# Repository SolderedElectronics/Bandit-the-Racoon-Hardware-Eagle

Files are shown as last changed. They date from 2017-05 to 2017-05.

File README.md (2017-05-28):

# Bandit the Racoon hardware (Eagle Files)
## Image
BTR image
[Bandit the Racoon board(101413)][board]

## Description and details
Bandit the Racoon is a cool looking board made for programming education which eliminates all need to work with hardware - everything is already connected and ready to use on the board. It can be programmed with block programming which is best for programming logic learning and with Arduino programming using Arduino library or using classic Arduino programming.
Onboard, there are many different sensors and actuators which can be used directly. All you need to do is connect the USB cable to the PC and you are ready to program and play! It supports battery power as well, there is battery charger onboard, so your projects can be portable.

###Specs:
- Temperature sensor
- Light sensor 
- Pushbutton
- Switch
- Potentiometer
- General input pins
- 12 RGB LED diodes arranged into a circle
- Buzzer
- General output pins
- I2C connector
- Atmega328 microcontroller
- CP2102 USB to UART bridge
- Lithium charger onboard

###Exact pins connections
If you wish to make your own Arduino code, here is list of all Arduino sensors and actuators and pins to which are they connected to. 
PINS

## Repository content
This repo contains Cadsoft Eagle .sch and .brd files for BTR board. It also contains schematic in .pdf created from .sch Eagle file. 
Files have been arranged into folders for navigating between different versions of board. 
Tip: layer 200 shows top silkscreen and layer 208 should be bottom silkscreen. tParts and bParts is not used.

## Docs
- [BTR product page][board]
- [BTR Arduino library][library]

## Board versions
- v1.0 - inital version

## License info
This product is open-source. Yay!
For any tech questions, contact us at techsupport@e-radionica.com
If you find an Issue, please open one at GitHub. If you can improve our product, fork it!

e-r.io Team.

[board]: https://e-radionica.com/en/bandit-the-raccoon-btr.html
[library]: https://github.com/e-radionicacom/Bandit-the-Racoon-Arduino-library

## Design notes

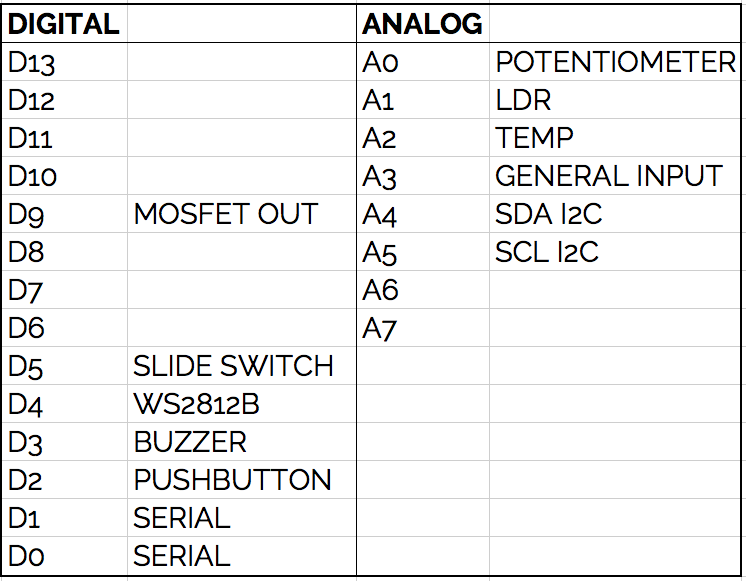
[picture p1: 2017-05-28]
v1.0/BTR_pins.png

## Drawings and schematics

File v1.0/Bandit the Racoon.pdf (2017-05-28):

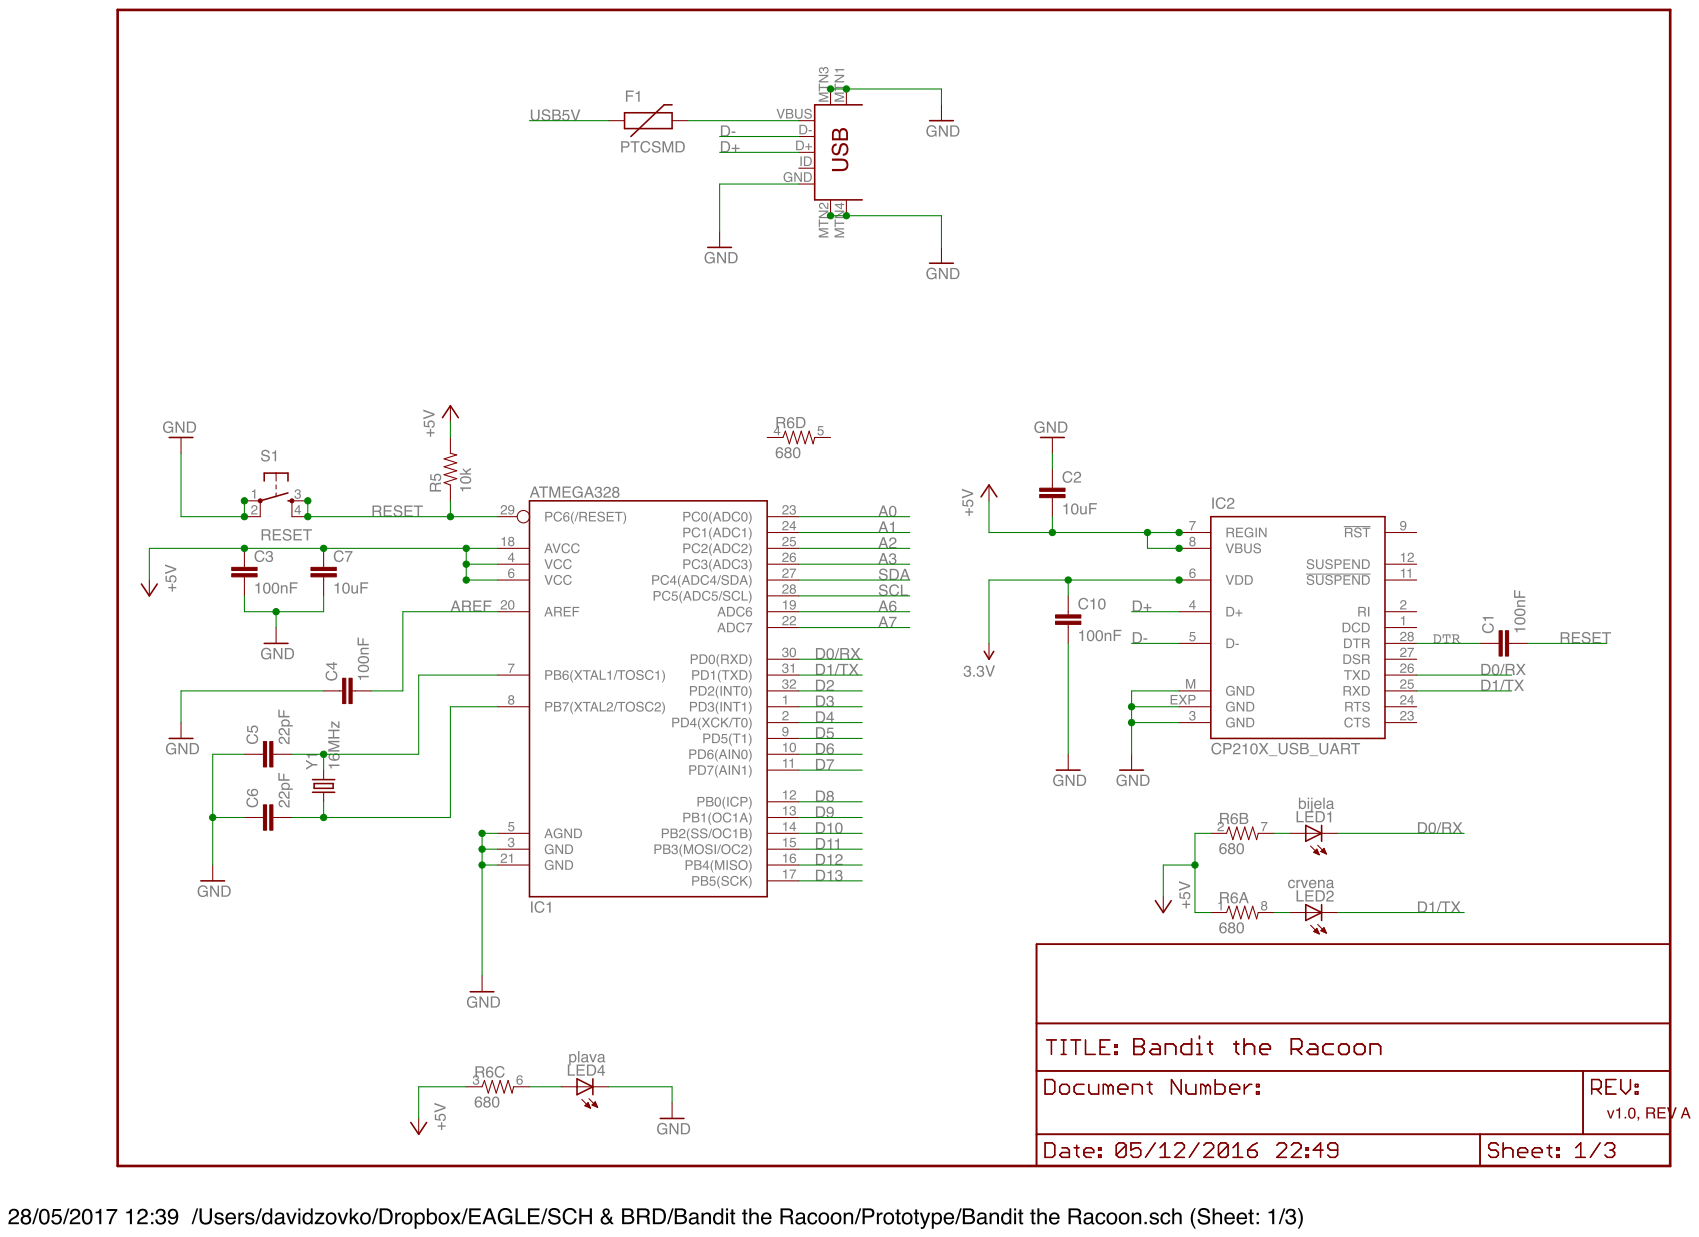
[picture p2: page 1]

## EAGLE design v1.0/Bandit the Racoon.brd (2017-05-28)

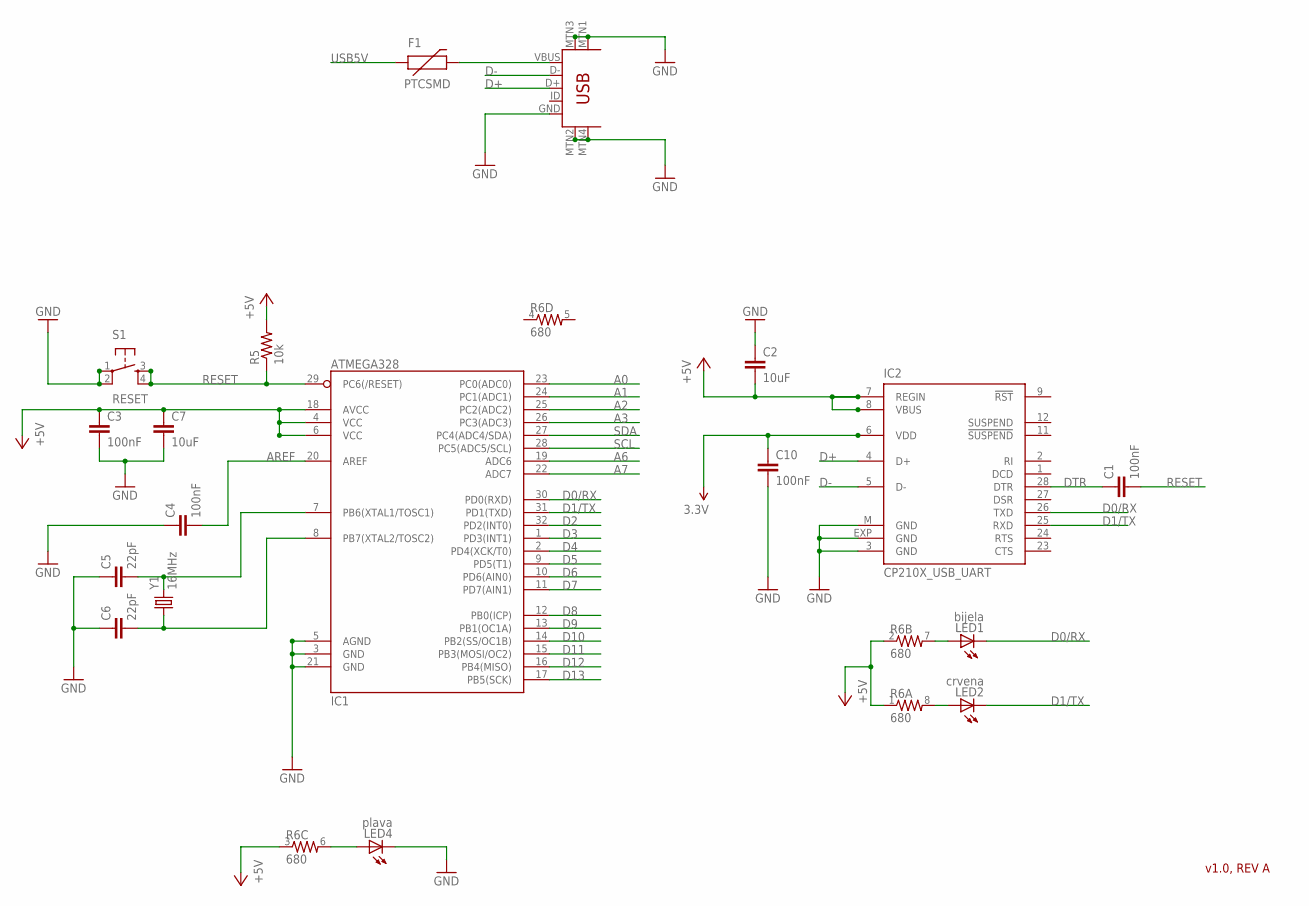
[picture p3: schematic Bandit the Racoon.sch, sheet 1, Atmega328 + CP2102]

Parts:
C1, C3, C4, C10: 100nF; 0603-CAP
C2, C7: 10uF; C3216
C5, C6: 22pF; 0603-CAP
F1: PTCSMD; PTC-1206
IC1: ATMEGA328; TQFP32-08
IC2: CP210X_USB_UART; MLP28
LED1: bijela; CHIP-LED0805
LED2: crvena; CHIP-LED0805
LED4: plava; CHIP-LED0805
R5: 10k; 0603-RES
R6: 680; 0603-ARV
S1: RESET; TACTILE_SWITCH_SMD
U1: USB-MINIB
Y1: 16MHz; CRYSTAL-SMD-5X3

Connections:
3.3V: C10.1, IC2.6 (VDD); also elsewhere on the board
+5V: C2.2, C3.1, C7.1, IC1.4 (VCC), IC1.6 (VCC), IC1.18 (AVCC), IC2.7 (REGIN), IC2.8 (VBUS), R5.2, R6.1, R6.2 (1), R6.3 (1); also elsewhere on the board
A0: IC1.23 (PC0(ADC0)); also elsewhere on the board
A1: IC1.24 (PC1(ADC1)); also elsewhere on the board
A2: IC1.25 (PC2(ADC2)); also elsewhere on the board
A3: IC1.26 (PC3(ADC3)); also elsewhere on the board
A6: IC1.19 (ADC6)
A7: IC1.22 (ADC7)
AREF: C4.2, IC1.20 (AREF)
CRYSTAL1: C5.2, IC1.7 (PB6(XTAL1/TOSC1)), Y1.3 (2)
CRYSTAL2: C6.2, IC1.8 (PB7(XTAL2/TOSC2)), Y1.1
D0/RX: IC1.30 (PD0(RXD)), IC2.26 (TXD), LED1.C; also elsewhere on the board
D1/TX: IC1.31 (PD1(TXD)), IC2.25 (RXD), LED2.C; also elsewhere on the board
D2: IC1.32 (PD2(INT0)); also elsewhere on the board
D3: IC1.1 (PD3(INT1)); also elsewhere on the board
D4: IC1.2 (PD4(XCK/T0)); also elsewhere on the board
D5: IC1.9 (PD5(T1)); also elsewhere on the board
D6: IC1.10 (PD6(AIN0))
D7: IC1.11 (PD7(AIN1))
D8: IC1.12 (PB0(ICP))
D9: IC1.13 (PB1(OC1A)); also elsewhere on the board
D10: IC1.14 (PB2(SS/OC1B))
D11: IC1.15 (PB3(MOSI/OC2))
D12: IC1.16 (PB4(MISO))
D13: IC1.17 (PB5(SCK))
D+: IC2.4 (D+), U1.D+
D-: IC2.5 (D-), U1.D-
DTR: C1.1, IC2.28 (DTR); also elsewhere on the board
GND: C2.1, C3.2, C4.1, C5.1, C6.1, C7.2, C10.2, IC1.3 (GND), IC1.5 (AGND), IC1.21 (GND), IC2.3 (GND), IC2.EXP (GND), IC2.M (GND), LED4.C, S1.1, S1.2, U1.GND, U1.MTN1 (MTN2), U1.MTN2 (MTN3), U1.MTN3 (MTN1), U1.MTN4; also elsewhere on the board
unnamed: LED1.A, R6.7 (2)
unnamed: LED2.A, R6.8 (2)
unnamed: F1.2, U1.VBUS
PLV_LED: LED4.A, R6.6 (2)
RESET: C1.2, IC1.29 (PC6(/RESET)), R5.1, S1.3, S1.4
SCL: IC1.28 (PC5(ADC5/SCL)); also elsewhere on the board
SDA: IC1.27 (PC4(ADC4/SDA)); also elsewhere on the board
USB5V: F1.1; also elsewhere on the board

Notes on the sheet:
v1.0, REV A

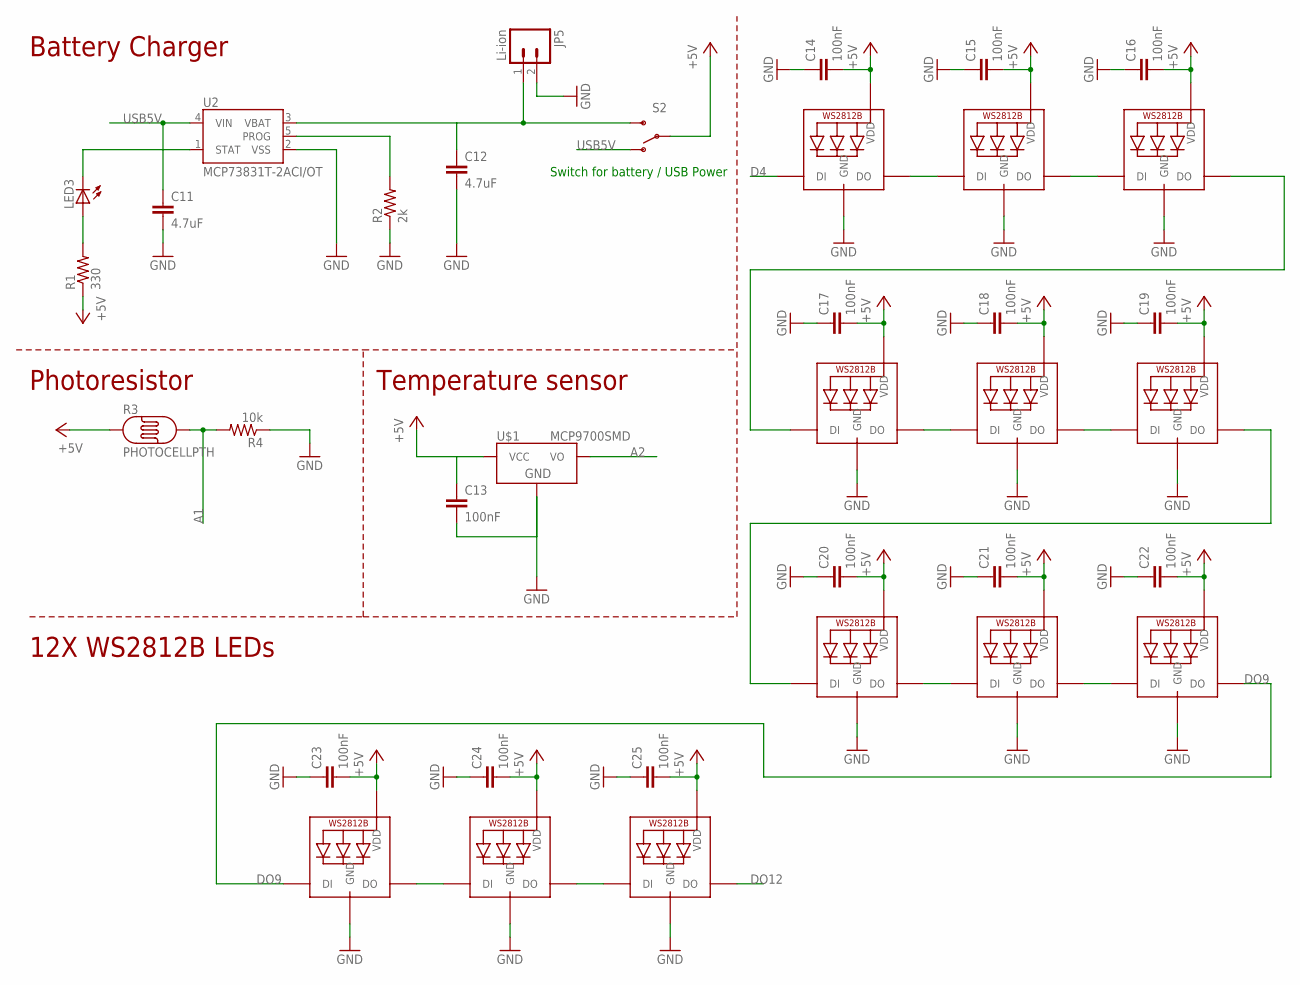
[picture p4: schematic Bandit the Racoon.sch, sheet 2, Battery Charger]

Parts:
C11, C12: 4.7uF; 0805
C13, C14, C15, C16, C17, C18, C19, C20, C21, C22, C23, C24, C25: 100nF; 0603-CAP
JP5: Li-ion; JST-2-PTH
LED3: LEDCHIPLED_0805; CHIPLED_0805
LED5, LED6, LED7, LED8, LED9, LED10, LED11, LED12, LED13, LED14, LED15, LED16: WS2812B5050; WS2812B
R1: 330; 0603-RES
R2: 2k; 0603-RES
R3: PHOTOCELLPTH; PHOTOCELL
R4: 10k; 0603-RES
S2: SWITCH-SPST-SMD-A
U2: MCP73831T-2ACI/OT; SOT23-5
U$1: MCP9700SMD; SOT23-3

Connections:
+5V: C13.1, C14.2, C15.2, C16.2, C17.2, C18.2, C19.2, C20.2, C21.2, C22.2, C23.2, C24.2, C25.2, LED5.1-VDD (VDD), LED6.1-VDD (VDD), LED7.1-VDD (VDD), LED8.1-VDD (VDD), LED9.1-VDD (VDD), LED10.1-VDD (VDD), LED11.1-VDD (VDD), LED12.1-VDD (VDD), LED13.1-VDD (VDD), LED14.1-VDD (VDD), LED15.1-VDD (VDD), LED16.1-VDD (VDD), R1.1, R3.1, S2.2, U$1.1 (VCC); also elsewhere on the board
A1: R3.2, R4.2; also elsewhere on the board
A2: U$1.2 (VO); also elsewhere on the board
D4: LED5.4-DIN (DI); also elsewhere on the board
DO1: LED5.2-DOUT (DO), LED6.4-DIN (DI)
DO2: LED6.2-DOUT (DO), LED7.4-DIN (DI)
DO3: LED7.2-DOUT (DO), LED8.4-DIN (DI)
DO4: LED8.2-DOUT (DO), LED9.4-DIN (DI)
DO5: LED9.2-DOUT (DO), LED10.4-DIN (DI)
DO6: LED10.2-DOUT (DO), LED11.4-DIN (DI)
DO7: LED11.2-DOUT (DO), LED12.4-DIN (DI)
DO8: LED12.2-DOUT (DO), LED13.4-DIN (DI)
DO9: LED13.2-DOUT (DO), LED14.4-DIN (DI)
DO10: LED14.2-DOUT (DO), LED15.4-DIN (DI)
DO11: LED15.2-DOUT (DO), LED16.4-DIN (DI)
DO12: LED16.2-DOUT (DO)
GND: C11.2, C12.2, C13.2, C14.1, C15.1, C16.1, C17.1, C18.1, C19.1, C20.1, C21.1, C22.1, C23.1, C24.1, C25.1, JP5.2, LED5.3-GND (GND), LED6.3-GND (GND), LED7.3-GND (GND), LED8.3-GND (GND), LED9.3-GND (GND), LED10.3-GND (GND), LED11.3-GND (GND), LED12.3-GND (GND), LED13.3-GND (GND), LED14.3-GND (GND), LED15.3-GND (GND), LED16.3-GND (GND), R2.1, R4.1, U2.2 (VSS), U$1.3 (GND); also elsewhere on the board
unnamed: LED3.C, U2.1 (STAT)
unnamed: LED3.A, R1.2
unnamed: C12.1, JP5.1, S2.3 (S), U2.3 (VBAT)
unnamed: R2.2, U2.5 (PROG)
USB5V: C11.1, S2.1 (O), U2.4 (VIN); also elsewhere on the board

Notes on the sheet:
Switch for battery / USB Power
Battery Charger
Photoresistor
Temperature sensor
12X WS2812B LEDs

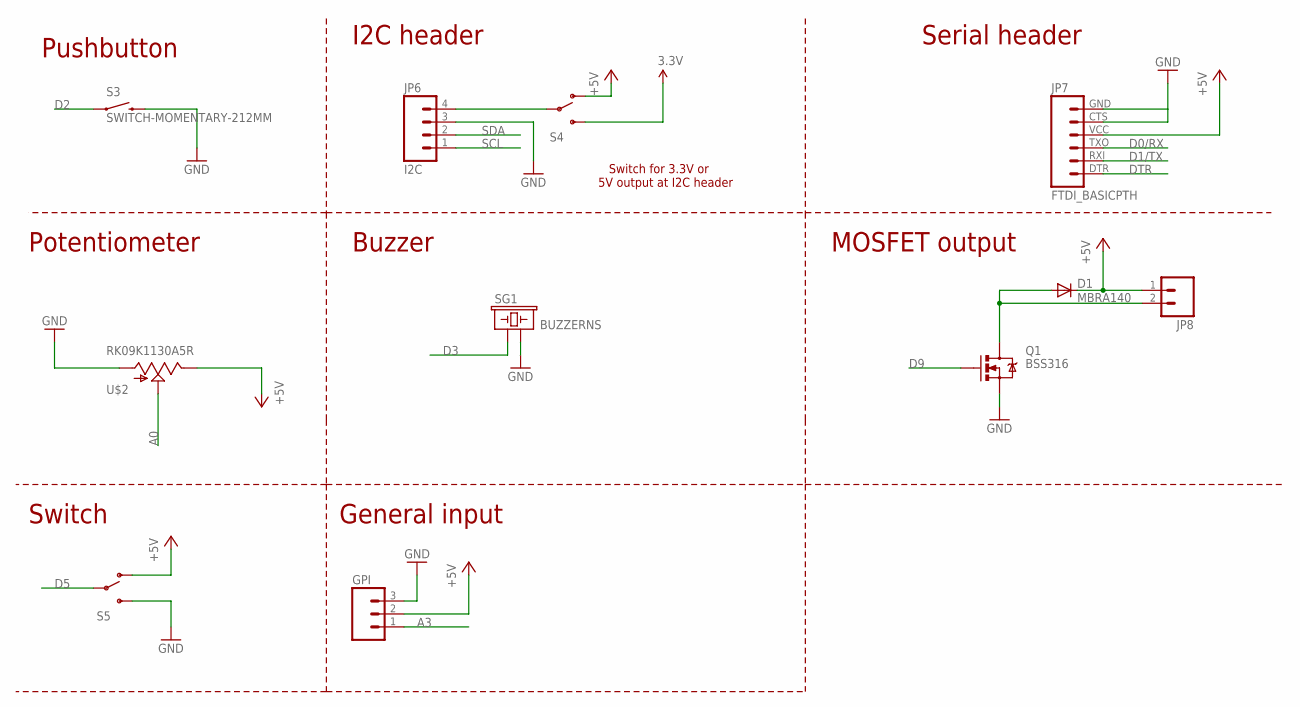
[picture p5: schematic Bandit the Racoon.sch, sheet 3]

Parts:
D1: MBRA140; SMA-DIODE
GPI: M03LONGPADS; 1X03_LONGPADS
JP6: I2C; 1X04_LONGPADS
JP7: FTDI_BASICPTH; FTDI_BASIC
JP8: M02PTH; 1X02
Q1: BSS316; SOT23-3
S3: SWITCH-MOMENTARY-212MM; TACTILE-PTH-12MM
S4: SWITCH-SPST-SMD-A
S5: SWITCH-SPSTKIT; SWITCH-SPDT_KIT
SG1: BUZZERNS; BUZZER-12MM-NS
U$2: RK09K1130A5R; ALPS_POT

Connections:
3.3V: S4.3 (S); also elsewhere on the board
+5V: D1.C, GPI.2, JP7.VCC (4), JP8.1, S4.1 (O), S5.1 (O), U$2.P$1 (E); also elsewhere on the board
A0: U$2.P$2 (S); also elsewhere on the board
A3: GPI.1; also elsewhere on the board
D0/RX: JP7.TXO (3); also elsewhere on the board
D1/TX: JP7.RXI (2); also elsewhere on the board
D2: S3.1; also elsewhere on the board
D3: SG1.+ (1); also elsewhere on the board
D5: S5.2; also elsewhere on the board
D9: Q1.1 (G); also elsewhere on the board
DTR: JP7.DTR (1); also elsewhere on the board
GND: GPI.3, JP6.3, JP7.CTS (5), JP7.GND (6), Q1.2 (S), S3.3 (2), S5.3 (S), SG1.- (2), U$2.P$3 (A); also elsewhere on the board
unnamed: JP6.4, S4.2
unnamed: D1.A, JP8.2, Q1.3 (D)
SCL: JP6.1; also elsewhere on the board
SDA: JP6.2; also elsewhere on the board

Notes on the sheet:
Pushbutton
Potentiometer
Buzzer
MOSFET output
Serial header
I2C header
Switch for 3.3V or 5V output at I2C header
Switch
General input

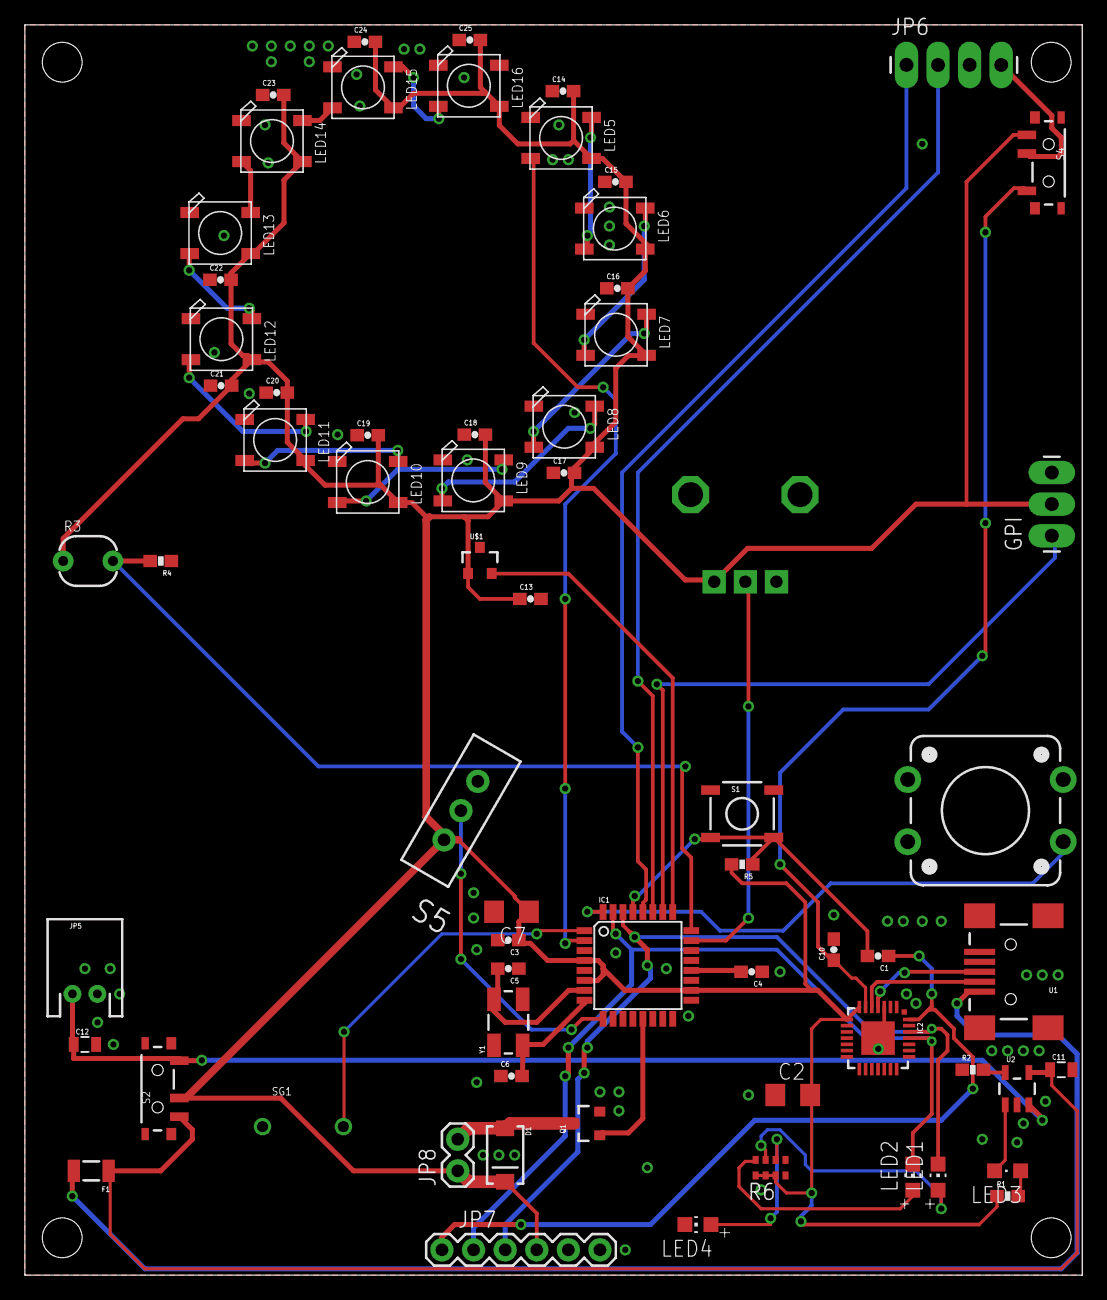
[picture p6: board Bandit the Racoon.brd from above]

Board: 2 copper layers, 85.0 x 100.5 mm, 72 parts (0 on the bottom side), 45 nets.

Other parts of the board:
U$3: BANDIT_THE_RACOON
U$4: E-RADIONICA.COM_MADE_IN_BACK!
U$5: OSH3MM
U$6: E-RADIONICA.COM_MADE_IN
U$7: NOVI_LOGO-4MM
U$8: LUDI_LOGO_BACK

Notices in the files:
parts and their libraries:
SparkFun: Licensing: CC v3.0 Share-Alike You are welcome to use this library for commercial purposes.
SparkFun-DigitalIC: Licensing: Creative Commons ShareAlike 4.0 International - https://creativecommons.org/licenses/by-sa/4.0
